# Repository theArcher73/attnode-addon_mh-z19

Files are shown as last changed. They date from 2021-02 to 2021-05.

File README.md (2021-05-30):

# CO<sub>2</sub>-Sensor-Attnode mit MH-Z19
A small functional AddOn CO<sub>2</sub>-Sensor to use with a [attno.de v3](https://attno.de) and MH-Z19-CO<sub>2</sub>-Sensor

 pictures from [@seiichiro0185](https://twitter.com/seiichiro0185?s=20) | &nbsp;
 ---------------------------------------------------------------------- | --------
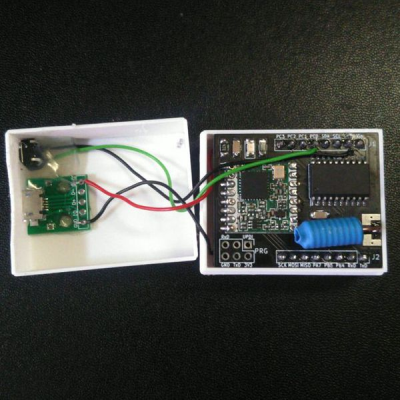
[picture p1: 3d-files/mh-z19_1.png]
MH-Z 19 offen
  | &nbsp;
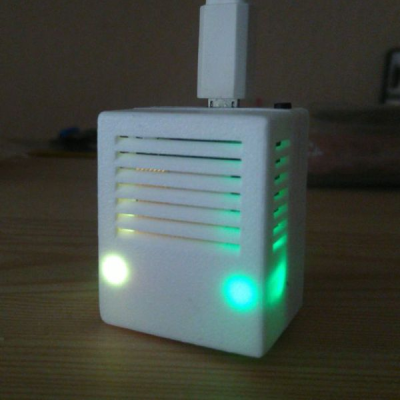
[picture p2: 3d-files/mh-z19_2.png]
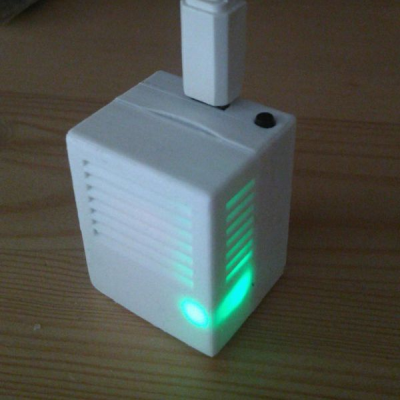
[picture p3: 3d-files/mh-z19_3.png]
  | 

You can find more information and the latest firmware at [attno.de v3](https://attno.de). [@seiichiro0185](https://twitter.com/seiichiro0185?s=20) is continuously developing the software, which is why it is only linked here.

This pcb allows the extension of the [attno.de v3](https://attno.de) with the possibility to be operated with 5V-15V operating voltage as well as CO<sub>2</sub> measurement by means of MH-Z19.

The measured values of the CO<sub>2</sub> sensor as well as the connection via LORAWAN<sup>(TM)</sup> can be visualized directly at the device by the integrated RGB-LED's, parallel to the transmission to a LoRa-Network-Server (LNS).

The use of the MH-Z19C is strongly recommended. However, this sensor drifts over time so regular calibration is required.
The sensor can be purchased over the Silk Road or directly from German dealers.

Special thanks to [@seiichiro0185](https://twitter.com/seiichiro0185?s=20), [@TwentySixer](https://twitter.com/Twenty_Sixer?s=20) and [@nottheedge](https://twitter.com/nottheedge?s=20) for their support.

front view | rear view
---------- | ---------
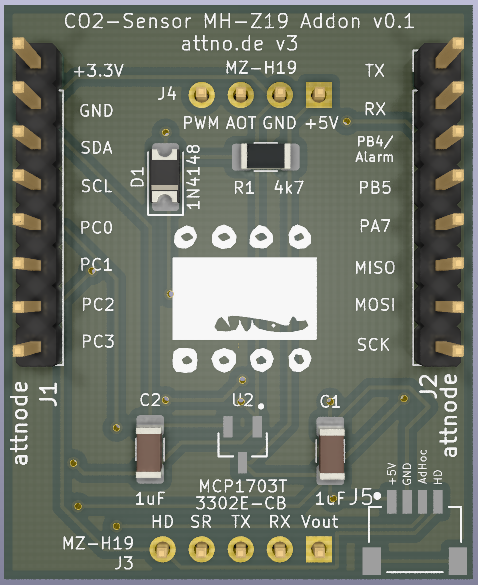
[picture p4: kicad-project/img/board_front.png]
front view
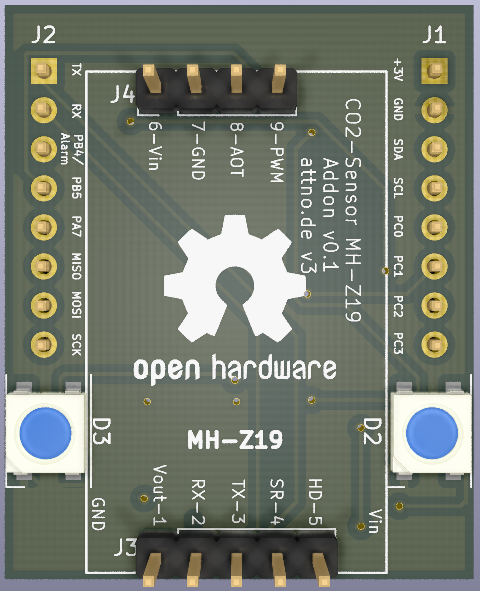
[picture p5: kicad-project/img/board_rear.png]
Rear view
 |  

In the folder 3d-files are stl-Files for a tiny housing from [@seiichiro](https://twitter.com/seiichiro0185).

 front-part MH-Z19C | rear-part CO<sub>2</sub>-Sensor Micro-USB | rear-part CO<sub>2</sub>-Sensor USB-C
 ------------------ | ----------------------------------------- | -------------------------------------
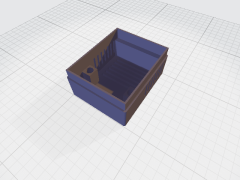
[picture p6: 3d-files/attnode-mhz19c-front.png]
MH-Z 19 front part
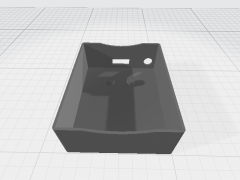
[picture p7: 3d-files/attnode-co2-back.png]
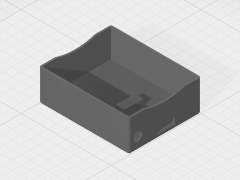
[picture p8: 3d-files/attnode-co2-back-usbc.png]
 |  |  
&nbsp; | [passende Breakout-Boards Micro-USB](https://www.amazon.de/dp/B07RDHNL9H/ref=cm_sw_r_oth_apip_Hl8EULSynzB3m) | [passende Breakout-Boards USB-C](https://www.amazon.de/dp/B01787RJW4/ref=cm_sw_r_oth_apip_VpbGjvT7G7Qvm)

The rear parts of the enclosures for Micro-USB or USB-C are planned for the use of ready-made breakout boards with USB-C or micro USB. The button for ad-hoc measurements or calibration can be glued into the housing.

LORAWAN is a registered trademark of [Semtech](https://www.semtech.com/)

## Disclaimer

The documentation of the CO<sub>2</sub>-Sensor-Attnode mit MH-Z19 is distributed in the hope that it will be useful, but WITHOUT ANY WARRANTY; without even the implied warranty of MERCHANTABILITY or FITNESS FOR A PARTICULAR PURPOSE.

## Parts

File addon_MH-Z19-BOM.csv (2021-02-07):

Reference | Quantity | Value | Description | Footprint
C1, C2 | 2 | 1µF | Capacitor SMD 1206 | Capacitor_SMD:C_1206_3216Metric_Pad1.33x1.80mm_HandSolder
D1 | 1 | 1N4148 | Diode SMD 1206 | Diode_SMD:D_1206_3216Metric_Pad1.42x1.75mm_HandSolder
D2, D3 | 2 | WS2812B | WS2812B | LED_SMD:LED_WS2812B_PLCC4_5.0x5.0mm_P3.2mm
J1 | 1 | attnode J1 | Pinheader Male 2,54mm 8 Pin | Connector_PinHeader_2.54mm:PinHeader_1x08_P2.54mm_Vertical
J2 | 1 | attnode J2 | Pinheader Male 2,54mm 8 Pin | Connector_PinHeader_2.54mm:PinHeader_1x08_P2.54mm_Vertical
J3 | 1 | MZ-H19 | Pinheader Male 2,54mm 5 Pin | Connector_PinHeader_2.54mm:PinHeader_1x05_P2.54mm_Vertical
J4 | 1 | MZ-H19 | Pinheader Male 2,54mm 4 Pin | Connector_PinHeader_2.54mm:PinHeader_1x04_P2.54mm_Vertical
J5 | 1 | SM04B-SRSS-TBT(LF)(SN) | JST 4pin Buchse horizontal | JST-SM04B-SRSS-TB_LF__SN:JST_SM04B-SRSS-TB(LF)(SN)
R1 | 1 | 4k7 | Resistor SMD 1206 | Resistor_SMD:R_1206_3216Metric_Pad1.30x1.75mm_HandSolder
U2 | 1 | MCP1703T-3302E_CB | LDO MCP 1703T-3302E_CB | MCP1703T-3302E_CB:SOT95P255X145-3N

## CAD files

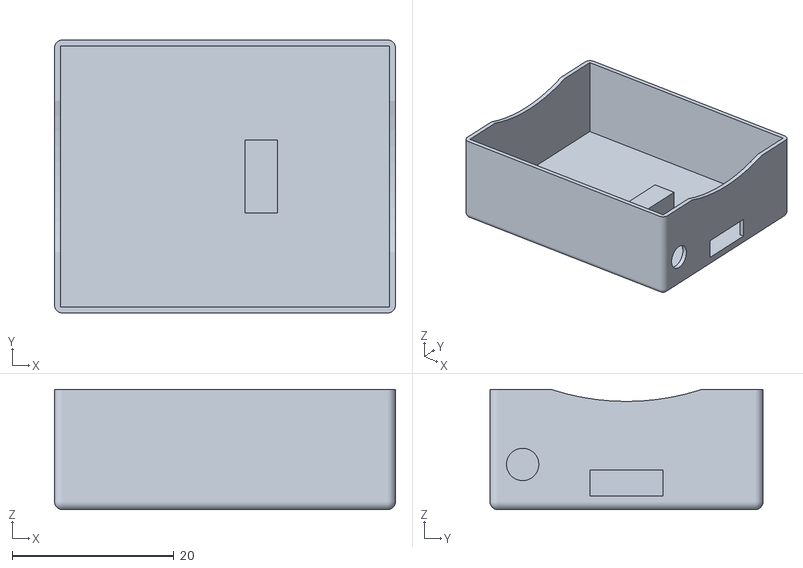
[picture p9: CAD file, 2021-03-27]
3d-files/attnode-co2-back-usbc.stl
42.2 x 33.8 x 14.9

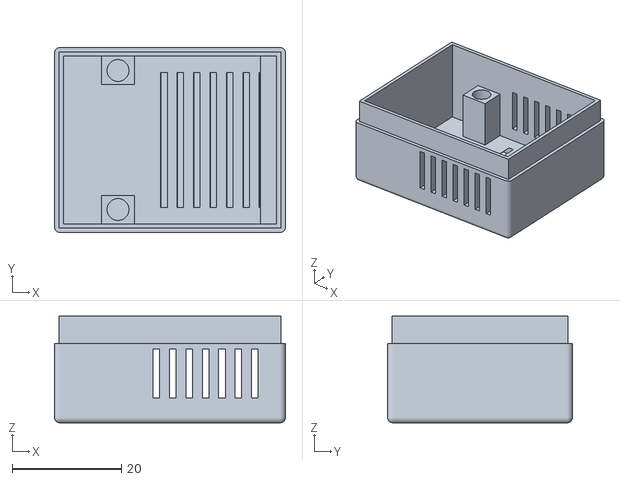
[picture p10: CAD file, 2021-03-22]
3d-files/attnode-mhz19c-front.stl
42.2 x 33.8 x 19.5

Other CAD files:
3d-files/attnode-co2-back.stl

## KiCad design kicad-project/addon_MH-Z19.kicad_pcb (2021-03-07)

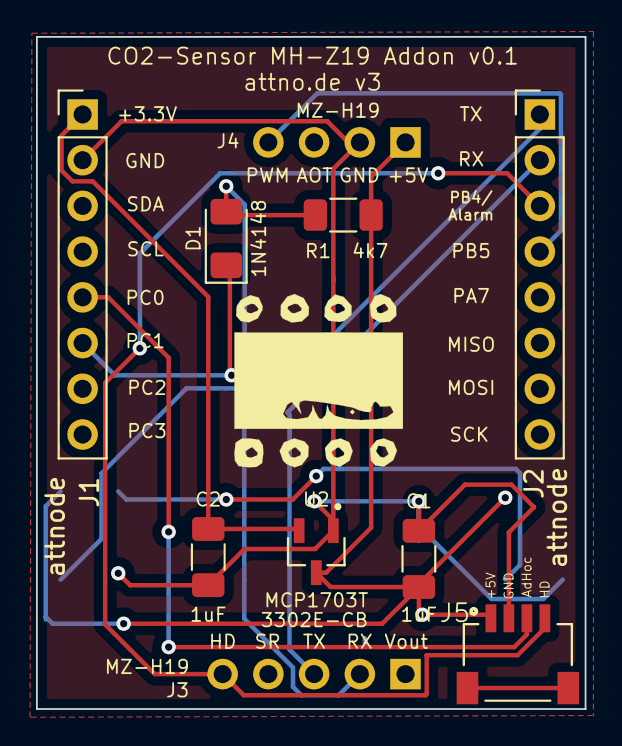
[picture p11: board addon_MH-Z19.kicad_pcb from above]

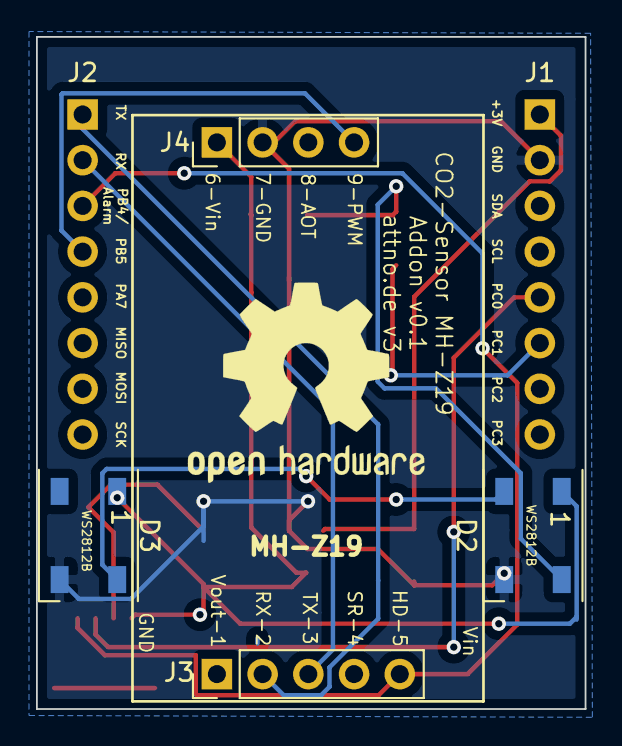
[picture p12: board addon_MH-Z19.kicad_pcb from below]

Board: 2 copper layers, 30.5 x 37.3 mm, 12 parts (4 on the bottom side), 12 nets.

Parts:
C1, C2: 1uF; C_1206_3216Metric_Pad1.33x1.80mm_HandSolder
D1: 1N4148; D_1206_3216Metric_Pad1.42x1.75mm_HandSolder
D2, D3: WS2812B; LED_WS2812B_PLCC4_5.0x5.0mm_P3.2mm
J1, J2: attnode; PinHeader_1x08_P2.54mm_Vertical
J3: MZ-H19; PinHeader_1x05_P2.54mm_Vertical
J4: MZ-H19; PinHeader_1x04_P2.54mm_Vertical
J5: SM04B-SRSS-TBT(LF)(SN); JST_SM04B-SRSS-TB(LF)(SN)
R1: 4k7; R_1206_3216Metric_Pad1.30x1.75mm_HandSolder
U2: MCP1703T; SOT95P255X145-3N

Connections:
+3V3: C2.1, J1.1, U2.2
+5V: C1.1, D2.1, D3.1, J4.1, J5.1, R1.1, U2.3
AdHoc: J1.5, J5.3
GND: C1.2, C2.2, D2.3, D3.3, J1.2, J4.2, J5.2, U2.1
HD: J2.3, J3.5, J5.4
unnamed: D1.2, D2.4, R1.2
unnamed: D2.2, D3.4
unnamed: J5.S1, J5.S2
PC1: D1.1, J1.6
PWM: J2.4, J4.4
RX: J2.2, J3.3
TX: J2.1, J3.2

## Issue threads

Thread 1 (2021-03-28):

Move AdHoc Button to PIN_PC2

seiichiro0185, 2021-03-28:
The AdHoc Button for triggering a Measurement immediately should be connected to PIN_PC2 on the ATTiny, since this Pin has the full support for all types of Interrupts to wake the MCU from sleep. It's also the default Pin for this purpose in the Firmware.

theArcher73, 2021-03-28:
I am currently waiting for the PCB's with the latest adjustments. When they arrive and everything works, I'll be happy to implement it, thank you!

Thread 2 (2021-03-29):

Adapting the sensor to a operating voltage tolerance between 3.3 - 12V

theArcher73, 2021-03-29:
The AttNo.de used in combination with the AddOn board is already able to work with operating voltages between 3.3-12V. Only the components on the AddOn PCB definitely require 5V. The goal should be to extend the operating voltage tolerance to all components of the node.

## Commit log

2021-02-07 initial build
    [CO2-PlatineMZ-H19-B_Cu.gbr, CO2-PlatineMZ-H19-B_Mask.gbr, CO2-PlatineMZ-H19-B_Paste.gbr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]
2021-02-07 added BOM
    [addon_MH-Z19.csv]
2021-03-27 update foldername to lcase
    [addon_MH-Z19-B_Cu.gbr, addon_MH-Z19-B_Mask.gbr, addon_MH-Z19-B_Paste.gbr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]
2021-03-27 added pictures 3d-parts
    [attnode-co2-back-usbc.stl]
